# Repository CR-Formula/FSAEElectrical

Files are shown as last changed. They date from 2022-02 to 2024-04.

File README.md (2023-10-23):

# ISU Formula SAE Electrical Repo
This repo contains all the embedded and software development we have produced for the FSAE Team for its Electrical subsystem on cars CR-26 and CR-27.

## What's all included?

### 3D Prints
Housing for our electrical equipment placed on the car or for hand-held use remotely.

### Logs
Logs in CSV format of live data from testing the car on campus and live performance at competitions.

### Printed Circuit Board Designs
Selected schematics and PCB files used in our live data collection.

### Module Tests
This is code we utilize to test whether our electrical equipment is set up correctly and helps us troubleshoot problems.

### Nextion
Utilizing a Nextion display on our vehicle, this is the most up-to-date version dashboard each driver utilizes while driving to monitor the car's performance.

### Telemetry
Embedded C++ software written to our ESPs & Arduinos to handle reading, converting, and transporting CAN data from the car to our displays.

### Telemetry Viewer
This is a forked repo from Farrel (http://www.farrellf.com). In our version, we have added more visual modules, changed the behavior of existing modules, and changed the theme of the software as well.

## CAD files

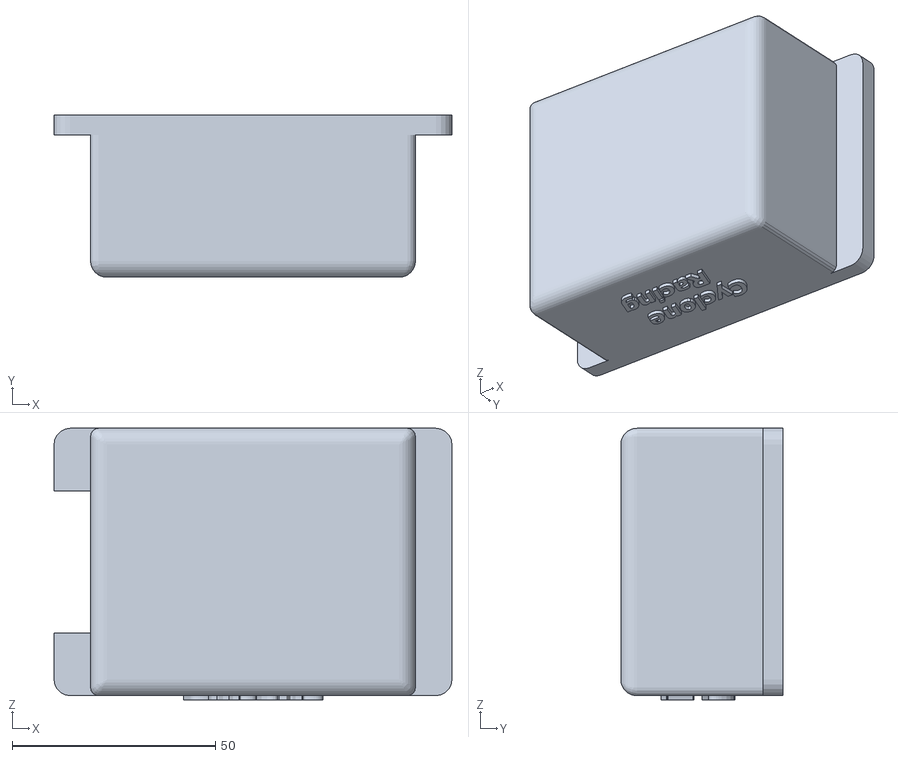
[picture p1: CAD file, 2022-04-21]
3D Prints/CR-26/Arduino_UnoLowerFinal2.stl
98.0 x 40.0 x 66.9

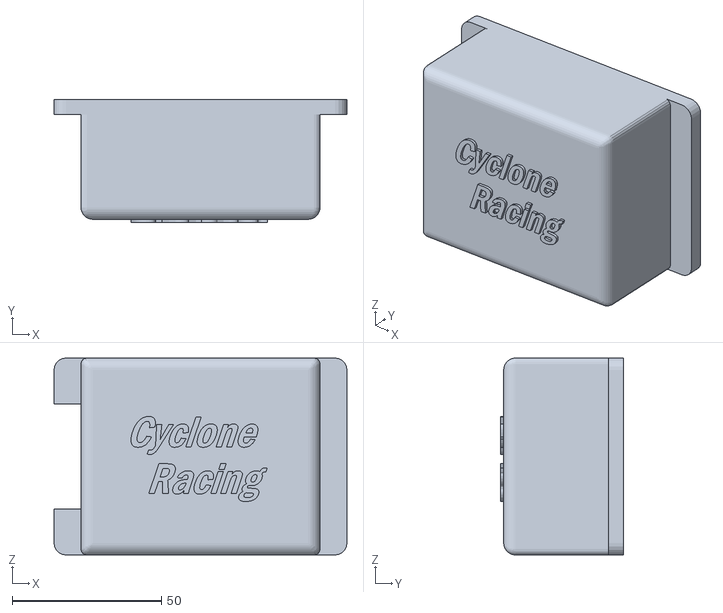
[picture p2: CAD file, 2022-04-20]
3D Prints/CR-26/Arduino_UnoLowerFinal.stl
98.0 x 41.0 x 65.9

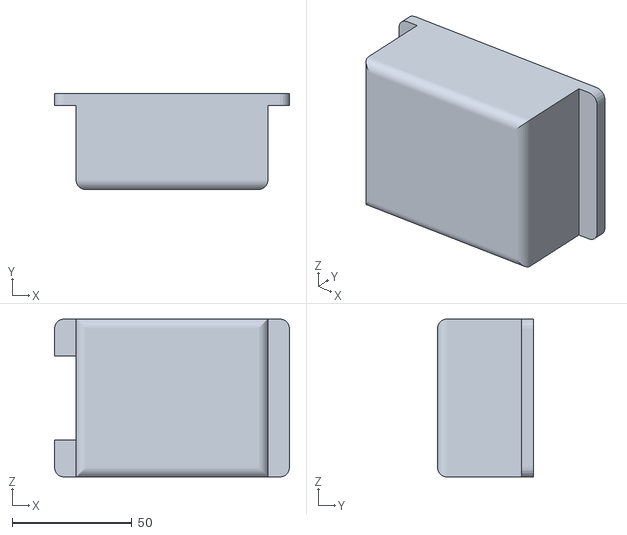
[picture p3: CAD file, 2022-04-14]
3D Prints/CR-26/Arduino_Unolower.stl
98.0 x 40.0 x 65.9

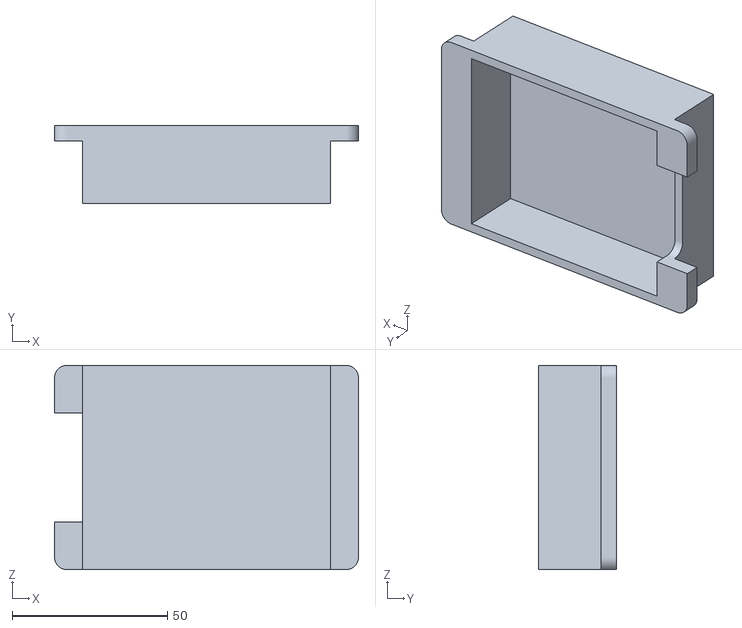
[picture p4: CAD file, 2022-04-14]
3D Prints/CR-26/Arduino_Uno_upper.stl
98.0 x 25.0 x 65.9

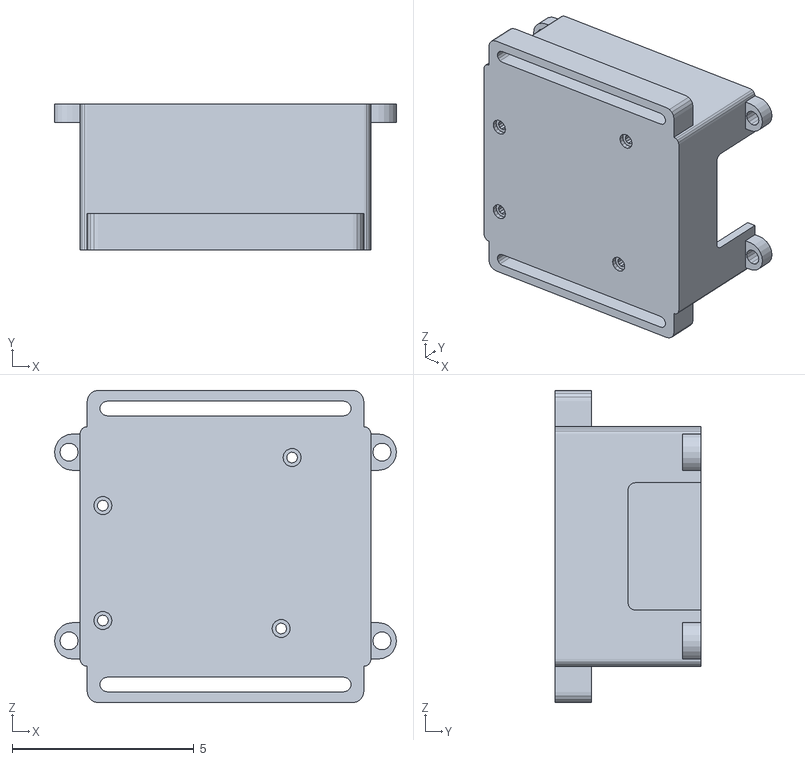
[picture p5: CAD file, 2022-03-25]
3D Prints/CR-26/Arduino_Uno2.stl
9.40 x 4.00 x 8.59

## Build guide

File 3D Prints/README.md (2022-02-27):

This folder is a place for all of Electrical to store 3D print files.
Currently just the arduino and ESP board boxes.

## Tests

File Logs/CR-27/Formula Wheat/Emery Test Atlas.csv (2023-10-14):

Format | AIM CSV File
Venue | Howe Hall International
Vehicle | CR27
User | Unknown
Data Source | AIM Data Logger
Comment | This data was sourced from Telemetry Viewer
Date | 2/5/1
Time | 11:12:13
Sample rate | 10000
Duration | 1.3343
Segment | NA
RPM | TPS | FOT | Ignition Angle | Lambda | AirT | CoolT | Latitude | Longitude | Speed | OilPressure | Fuel Pressure | Front Left Temp | Front Right Temp | Rear Left Temp | Rear Right Temp | Front Right Damper | Front Left Damper | Rear Right Damper | Rear Left Damper | Brake Pressure Front | Brake Pressure Rear | Brake Bias | AccX | AccY | AccZ | GyroX | GyroY | GyroZ | MagX | MagY | MagZ
RPM | TPS | FOT | Ignition Angle | Lambda | AirT | CoolT | Latitude | Longitude | Speed | OilPressure | Fuel Pressure | Front Left Temp | Front Right Temp | Rear Left Temp | Rear Right Temp | Front Right Damper | Front Left Damper | Rear Right Damper | Rear Left Damper | Brake Pressure Front | Brake Pressure Rear | Brake Bias | AccX | AccY | AccZ | GyroX | GyroY | GyroZ | MagX | MagY | MagZ
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

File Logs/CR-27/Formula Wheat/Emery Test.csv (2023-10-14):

Sample Number (10000 samples per second) | UNIX Timestamp (Milliseconds since 1970-01-01) | RPM (rpm) | TPS (%) | FOT (ms) | Ignition Angle (deg) | Lambda (Lambda) | AirT (C) | CoolT (C) | Latitude (Deg) | Longitude (Deg) | Speed (mph) | OilPressure (psi) | Fuel Pressure (psi) | Front Left Temp (C) | Front Right Temp (C) | Rear Left Temp (C) | Rear Right Temp (C) | Front Right Damper (mm) | Front Left Damper (mm) | Rear Right Damper (mm) | Rear Left Damper (mm) | Brake Pressure Front (psi) | Brake Pressure Rear (psi) | Brake Bias (%) | AccX (g) | AccY (g) | AccZ (g) | GyroX (deg) | GyroY (deg) | GyroZ (deg) | MagX (gauss) | MagY (gauss) | MagZ (gauss)0 | 1696179264662 | 0.0 | 0.0 | 0.0 | 0.0 | 0.0 | 0.0 | 0.0 | 0.0 | 0.0 | 0.0 | 0.0 | 0.0 | 0.0 | 0.0 | 0.0 | 0.0 | 0.0 | 0.0 | 0.0 | 0.0 | 0.0 | 0.0 | 0.0 | 0.0 | 0.0
1 | 1696179264662 | 0.0 | 0.0 | 0.0 | 0.0 | 0.0 | 0.0 | 0.0 | 0.0 | 0.0 | 0.0 | 0.0 | 0.0 | 0.0 | 0.0 | 0.0 | 0.0 | 0.0 | 0.0 | 0.0 | 0.0 | 0.0 | 0.0 | 0.0 | 0.0 | 0.0 | 0.0 | 0.0 | 0.0 | 0.0 | 0.0 | 0.0 | 0.0
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

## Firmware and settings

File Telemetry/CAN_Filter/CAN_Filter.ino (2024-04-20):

/*Iowa State Formula SAE Electrical Subsystem*/

#include <mcp_can.h> // CAN Bus Library
#include <SPI.h> // SPI Library
#include <Adafruit_LSM9DS1.h> // IMU Library
#include <Adafruit_Sensor.h> // Sensor Library
#include <RH_RF95.h> // LoRa Library
#include <math.h> // Math Library
#include <stdio.h> // Standard I/O Library
#include <stdlib.h> // Standard Library

#define FR_THERMO A1
#define ACC_X A15
#define ACC_Y A13
#define ACC_Z A14
#define FR_POT A12
#define RR_POT A12

void Accel_Cal(); // Calibrate Accelerometer
void Accel_Read(); // Read Accelerometer
void CAN_Data(); // Read in CAN Data
void Telemetry_Filter(); // Filter out extraneous values
void Send_Dash(); // Send values to update the dash display
void Suspension_Pot(); // Read in analog Suspension Damper Potentiometers
void Brake_Pressure(); // Read in analog Brake Pressure values
void Lora_Send(); // Send data over LoRa
void Print_Test_Data(); // Print test data to validate connections

// Stores the CAN Packet ID
long unsigned int rxId;
unsigned char len = 0;
// Length of the Buffer for Packet Data
unsigned char rxBuf[8];
// Stores the CAN packet serial message
char msgString[128];
static const int RxPin = 3;
static const int TxPin = 4;

// Sets INT to pin 2
#define CAN0_INT    2
// Sets CS
// MCP_CAN CAN0(10); // Uno
MCP_CAN CAN0(53); // Mega

// Defines for the LoRa Module Pins
#define RFM95_CS    49
#define RFM95_INT   3
#define RFM95_RST   7
#define RF95_FREQ   915.0

RH_RF95 rf95(RFM95_CS, RFM95_INT); // LoRa Module

// Holds all calculated Telemetry Data
typedef struct data_struct
{
  float RPM;           // RPM
  float TPS;           // TPS
  float FOT;           // Fuel Open Time
  float IA;            // Ignition Angle
  float Lam;           // Lambda
  float AirT;          // Air Temp
  float CoolT;         // Coolant Temp
  float Speed;         // Vehicle Speed
  float OilP;          // Oil Pressure
  float FRTemp;        // Front Right Brake Temp
  float RRTemp;        // Rear Right Brake Temp
  float FRPot;         // Front Right Suspension Damper
  float RRPot;         // Rear Right Suspension Damper
  float AccX;          // Accelerometer X Axis
  float AccZ;          // Accelerometer Z Axis
  float AccY;          // Accelerometer Y Axis
} data_struct;
data_struct telemetry;

// Stores Calculated Brake Bias Value
double brakeBias = 0;

// Variables used for filtering out extraneous values
int RPMLast;
float TPSLast;
float FOTLast;
float IALast;
float LamLast;
float AirTLast;
float CoolTLast;
float OilPLast;

// Variables for Accelerometer
int     XYZ_RAW[3];
int     XYZ_Cal_Offset[3];
double  XYZ_G[3];
uint8_t CALIBRATION_DONE;

char message[64]; // Buffer for Dash Message

char buf[sizeof(telemetry)]; // Buffer for data transmission

/**
 * @brief Initialize Peripherials and Sensors
 */
void setup() {
  Serial2.begin(115200); // Serial port 2 for Nextion

  // Init LoRa Module reset pin
  pinMode(RFM95_RST, OUTPUT);
  digitalWrite(RFM95_RST, HIGH);

  // Initializes MCP2515 running at 16MHz with a baudrate of 250kb/s and the masks and filters disabled.
  if (CAN0.begin(MCP_ANY, CAN_250KBPS, MCP_16MHZ) == CAN_OK)
    Serial.println("MCP2515 Initialized Successfully!");
  else
    Serial.println("Error Initializing MCP2515...");

  // Set MCP2515 operation to normal
  CAN0.setMode(MCP_NORMAL);

  // Configure the INT input pin
  pinMode(CAN0_INT, INPUT);

  // Reset LoRa Module
  digitalWrite(RFM95_RST, LOW);
  delay(10);
  digitalWrite(RFM95_RST, HIGH);
  delay(10);

  // Configure the LoRa Module
  while (!rf95.init()) {
    Serial.println("LoRa radio init failed");
    while (1);
  }
  Serial.println("LoRa radio init OK!");

  if (!rf95.setFrequency(RF95_FREQ)) {
    Serial.println("setFrequency failed");
    while (1);
  }
  Serial.print("Set Freq to: "); Serial.println(RF95_FREQ);
  rf95.setTxPower(23, false);
  // TODO: Look into Spreading Factor and bandwidth settings
  // SF11/500kHz  bitrate: 1760 Max   Payload Size: 109

  // Initialize Accelerometer
  CALIBRATION_DONE = 0;
  Serial.begin(115200);
  Accel_Cal();
}

/**
 * @brief Function to read Data fron PE3 ECU
 * @note All 2 byte data is stored [LowByte, HighByte]
 * @note Num = (LowByte + HighByte * 256) * resolution
 */
void CAN_Data() {
  if (!digitalRead(CAN0_INT))
  {
    // Read Id, length, and message data
    CAN0.readMsgBuf(&rxId, &len, rxBuf);

    // check for specific CAN ID. pull needed data, and repackage the data
    // Change if added Sensors
    if ((rxId & 0x1FFFFFFF) == 0x0CFFF048) {
      telemetry.RPM = (rxBuf[0] + rxBuf[1] * 256); // RPM
      telemetry.TPS = (rxBuf[2] + rxBuf[3] * 256) * 0.1; // Throttle Position Sensor
      telemetry.FOT = (rxBuf[4] + rxBuf[5] * 256) * 0.1; // Fuel Open Time
      telemetry.IA = (rxBuf[6] + rxBuf[7] * 256) * 0.1; // Igition Angle
    }
    if ((rxId & 0x1FFFFFFF) == 0x0CFFF148) {
      telemetry.Lam = (rxBuf[4] + rxBuf[5] * 256) * 0.001; // Lambda
    }
    if ((rxId & 0x1FFFFFFF) == 0x0CFFF548) {
      telemetry.AirT = (rxBuf[2] + rxBuf[3] * 256) * 0.1; // Air Temp
      telemetry.CoolT = (rxBuf[4] + rxBuf[5] * 256) * 0.1; // Coolant Temp
    }
    if ((rxId & 0x1FFFFFFF) == 0x0CFFF348) { 
      telemetry.OilP = (((rxBuf[6] + rxBuf[7] * 256) * 0.001) - .5) / 4.0 * 150.0; // Oil Pressure PSI
    }
  }
}

/**
 * @brief Reads data from the Analog Accelerometer
 * @note Applies calibration offset
 * 
 */
void Accel_Read() {
  telemetry.AccX = ((float)(analogRead(ACC_X) - XYZ_Cal_Offset[0]) / 170.667); /* Acceleration in g units */
  telemetry.AccY = ((float)(analogRead(ACC_Y) - XYZ_Cal_Offset[1]) / 170.667);
  telemetry.AccZ = ((float)(analogRead(ACC_Z) - XYZ_Cal_Offset[2]) / 170.667);
}

/**
 * @brief Calibrate Accelerometer
 * @note Reads in 5 values and averages them
 * 
 */
void Accel_Cal() {

  for (int i = 0; i < 5; i++) {
    XYZ_Cal_Offset[0] += analogRead(ACC_X);
    XYZ_Cal_Offset[1] += analogRead(ACC_Y);
    XYZ_Cal_Offset[2] += analogRead(ACC_Z);
  }

  XYZ_Cal_Offset[0] = XYZ_Cal_Offset[0] / 5;
  XYZ_Cal_Offset[1] = XYZ_Cal_Offset[1] / 5;
  XYZ_Cal_Offset[2] = XYZ_Cal_Offset[2] / 5;

  delay(1);
  CALIBRATION_DONE = 1;
}

/**
 * @brief Function to filter out extraneous values
 * @note Originaly written to reduce Time Slicing
 */
void Telemetry_Filter() {
  if (telemetry.RPM > 20000) {
      telemetry.RPM = RPMLast;
    }
    if (abs(TPSLast - telemetry.TPS) > 90 && TPSLast > 0) {
      telemetry.TPS = TPSLast;
    }
    if (abs(FOTLast - telemetry.FOT) > 10 && FOTLast > 0) {
      telemetry.FOT = FOTLast;
    }
    if (abs(IALast - telemetry.IA) > 50 && IALast > 0 || telemetry.IA > 40) {
      telemetry.IA = IALast;
    }
    if (abs(LamLast - telemetry.Lam) > 1 && LamLast > 0) {
      telemetry.Lam = LamLast;
    }
    if (abs(AirTLast - telemetry.AirT) > 25 && AirTLast > 0) {
      telemetry.AirT = AirTLast;
    }
    if (abs(CoolTLast - telemetry.CoolT) > 50 && CoolTLast > 0) {
      telemetry.CoolT = CoolTLast;
    }

  // Save last filtered values
  RPMLast = telemetry.RPM;
  TPSLast = telemetry.TPS;
  FOTLast = telemetry.FOT;
  IALast = telemetry.IA;
  LamLast = telemetry.Lam;
  AirTLast = telemetry.AirT;
  CoolTLast = telemetry.CoolT;
  OilPLast = telemetry.OilP;
}

/**
 * @brief Writes End Command to the Nextion Display
 */
void Nextion_CMD() {
    Serial2.write(0xff);
    Serial2.write(0xff);
    Serial2.write(0xff);
}

/**
 * @brief Send Data to the Dash
 * @note The telemetry values have to match Nextion Object names
 * @todo Add shift light functionality
 */
void Send_Dash() {
  // Send dash values as text objects

  sprintf(message, "%d\"", (int)telemetry.RPM);
  Serial2.print("rpm.txt=\"");
  Serial2.print(message); 
  Nextion_CMD();

  sprintf(message, "%d\"", (int)telemetry.CoolT);
  Serial2.print("waterTemp.txt=\"");
  Serial2.print(message);
  Nextion_CMD();

  sprintf(message, "%d\"", (int)telemetry.OilP);
  Serial2.print("oilPress.txt=\"");
  Serial2.print(message);
  Nextion_CMD();

  sprintf(message, "%d\"", (int)telemetry.FRTemp);
  Serial2.print("brakeFR.txt=\"");
  Serial2.print(message);
  Nextion_CMD();

  sprintf(message, "%d\"", (int)telemetry.RRTemp);
  Serial2.print("brakeRR.txt=\"");
  Serial2.print(message);
  Nextion_CMD();

  int rpmBar = telemetry.RPM / 160;
  Serial2.print("rpmBar.val=");
  Serial2.print(rpmBar);
  Nextion_CMD();

  // Send value for shift lights
  // Shift light range from 8525 - 15500
  if (telemetry.RPM > 7750) {
    int shiftlights = ((telemetry.RPM - 7750) * 80) / 7750;
    digitalWrite(5, shiftlights);
  }
}

/**
 * @brief Reads in suspension potentiometer values
 * @todo verify conversions
 */
void Suspension_Pot() {
  // telemetry.FLPot = ((double)analogRead(A0) * 50.0) / 1023.0;
  telemetry.FRPot = ((double)analogRead(FR_POT) * 50.0) / 1023.0;
  // telemetry.RLPot = ((double)analogRead(A2) * 50.0) / 1023.0;
  telemetry.RRPot = ((double)analogRead(RR_POT) * 50.0) / 1023.0;
}

/**
 * @brief Send the LoRa Packet
 * 
 */
void Lora_Send() {
  memcpy(buf, &telemetry, sizeof(telemetry)); // Copy data from struct
  rf95.send((uint8_t *)buf, sizeof(buf)); // Send Data
}

/**
 * @brief Caclulate Brake Temperature
 * @note Uses a thermocouple to calculate temperature
 * 
 */
void Brake_Temp() {
  int FRTemp = analogRead(FR_THERMO);

  // T = (V - 1.25) / .005
  telemetry.FRTemp = ((((double)FRTemp * 5) / 1023.0) - 1.25) / .005;
}

/**
 * @brief Function to print test data for debug
 * @note Comment this out when you upload to the car
 */
void Print_Test_Data() {
  Serial.println();
  Serial.println(telemetry.TPS);
  Serial.println(telemetry.FRTemp);
  Serial.println(brakeBias);
  Serial.println();
}

/**
 * @brief Super loop that calls all the telemetry functions
 * 
 */
void loop() {
  // function calls for each sensor/module
  CAN_Data();
  Brake_Temp();
  // Telemetry_Filter();
  // Suspension_Pot();
  Accel_Read();
  // Send_Dash();
  Lora_Send();

  Print_Test_Data();
  
  delay(1); // Delay for stability
}

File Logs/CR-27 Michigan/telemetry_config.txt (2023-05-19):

Telemetry Viewer v0.7 Settings

GUI Settings:

	tile column count = 6
	tile row count = 6
	time format = Only Time
	show 24-hour time = false
	show plot tooltips = true
	smooth scrolling = true
	show fps and period = false
	chart index for benchmarks = -1
	antialiasing level = 16

Communication Settings:

	port = UART: COM3
	uart baud rate = 115200
	tcp/udp port number = 8080
	packet type = CSV
	sample rate = 10000

11 Data Structure Locations:

	location = 0
	binary processor = null
	name = RPM
	color = 0xFF0000
	unit = rpm
	conversion factor a = 1.0
	conversion factor b = 1.0

	location = 1
	binary processor = null
	name = TPS
	color = 0xFF00FF
	unit = %
	conversion factor a = 1.0
	conversion factor b = 1.0

	location = 2
	binary processor = null
	name = Fuel Open Time
	color = 0x3333FF
	unit = ms
	conversion factor a = 1.0
	conversion factor b = 1.0

	location = 3
	binary processor = null
	name = Ignition Angle
	color = 0x66FF33
	unit = deg
	conversion factor a = 1.0
	conversion factor b = 1.0

	location = 4
	binary processor = null
	name = Lambda
	color = 0xFF9933
	unit = Lambda
	conversion factor a = 1.0
	conversion factor b = 1.0

	location = 5
	binary processor = null
	name = Air Temp
	color = 0x33FFFF
	unit = deg
	conversion factor a = 1.0
	conversion factor b = 1.0

	location = 6
	binary processor = null
	name = Coolant Temp
	color = 0x00CC00
	unit = deg
	conversion factor a = 1.0
	conversion factor b = 1.0

	location = 7
	binary processor = null
	name = Lat
	color = 0x009999
	unit = Deg
	conversion factor a = 1.0
	conversion factor b = 1.0

	location = 8
	binary processor = null
	name = Lng
	color = 0x009999
	unit = Deg
	conversion factor a = 1.0
	conversion factor b = 1.0

	location = 9
	binary processor = null
	name = Speed
	color = 0x009999
	unit = mph
	conversion factor a = 1.0
	conversion factor b = 1.0

	location = 10
	binary processor = null
	name = Oil Pressure
	color = 0xFF66FF
	unit = psi
	conversion factor a = 1.0
	conversion factor b = 1.0

Checksum:

	location = -1
	checksum processor = null

8 Charts:

	chart type = Dial
	top left x = 0
	top left y = 0
	bottom right x = 1
	bottom right y = 1
	normal datasets = 0
	bitfield edge states = 
	bitfield level states = 
	autoscale dial minimum = false
	manual dial minimum = 0.0
	autoscale dial maximum = false
	manual dial maximum = 15000.0
	sample count = 1000
	show dataset label = true
	show reading label = true
	show min/max labels = true
	show statistics = true

	chart type = Time Domain
	top left x = 2
	top left y = 0
	bottom right x = 3
	bottom right y = 1
	normal datasets = 5
	bitfield edge states = 
	bitfield level states = 
	duration type = Seconds
	duration = 3.0
	x-axis = Timestamps
	autoscale y-axis minimum = true
	manual y-axis minimum = -1.0
	autoscale y-axis maximum = true
	manual y-axis maximum = 1.0
	show x-axis title = true
	show x-axis scale = true
	show y-axis title = true
	show y-axis scale = true
	show legend = true
	cached mode = false
	over max warning = false
	max amount = 220

	chart type = Time Domain
	top left x = 4
	top left y = 0
	bottom right x = 5
	bottom right y = 1
	normal datasets = 6
	bitfield edge states = 
	bitfield level states = 
	duration type = Seconds
	duration = 3.0
	x-axis = Timestamps
	autoscale y-axis minimum = true
	manual y-axis minimum = -1.0
	autoscale y-axis maximum = true
	manual y-axis maximum = 1.0
	show x-axis title = true
	show x-axis scale = true
	show y-axis title = true
	show y-axis scale = true
	show legend = true
	cached mode = false
	over max warning = false
	max amount = 220

	chart type = Time Domain
	top left x = 2
	top left y = 2
	bottom right x = 3
	bottom right y = 3
	normal datasets = 2
	bitfield edge states = 
	bitfield level states = 
	duration type = Seconds
	duration = 3.0
	x-axis = Timestamps
	autoscale y-axis minimum = true
	manual y-axis minimum = -1.0
	autoscale y-axis maximum = true
	manual y-axis maximum = 1.0
	show x-axis title = true
	show x-axis scale = true
	show y-axis title = true
	show y-axis scale = true
	show legend = true
	cached mode = false
	over max warning = false
	max amount = 220

	chart type = Dial
	top left x = 4
	top left y = 2
	bottom right x = 5
	bottom right y = 3
	normal datasets = 3
	bitfield edge states = 
	bitfield level states = 
	autoscale dial minimum = false
	manual dial minimum = 10.0
	autoscale dial maximum = false
	manual dial maximum = 40.0
	sample count = 1000
	show dataset label = true
	show reading label = true
	show min/max labels = true
	show statistics = true

	chart type = Dial
	top left x = 0
	top left y = 2
	bottom right x = 1
	bottom right y = 3
	normal datasets = 1
	bitfield edge states = 
	bitfield level states = 
	autoscale dial minimum = false
	manual dial minimum = 0.0
	autoscale dial maximum = false
	manual dial maximum = 100.0
	sample count = 1000
	show dataset label = true
	show reading label = true
	show min/max labels = true
	show statistics = true
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

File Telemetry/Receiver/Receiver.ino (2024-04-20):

#include <SPI.h>
#include <RH_RF95.h>

// Uno
#define RFM95_CS    4
#define RFM95_INT   3
#define RFM95_RST   2
#define RF95_FREQ 915.0

typedef struct data_struct
{
  float RPM;           // RPM
  float TPS;           // TPS
  float FOT;           // Fuel Open Time
  float IA;            // Ignition Angle
  float Lam;           // Lambda
  float AirT;          // Air Temp
  float CoolT;         // Coolant Temp
  float Speed;         // Vehicle Speed
  float OilP;          // Oil Pressure
  float FRTemp;        // Front Right Brake Temp
  float RRTemp;        // Rear Right Brake Temp
  float FRPot;         // Front Right Suspension Damper
  float RRPot;         // Rear Right Suspension Damper
  float AccX;          // Accelerometer X Axis
  float AccZ;          // Accelerometer Z Axis
  float AccY;          // Accelerometer Y Axis
} data_struct;
data_struct telemetry;

uint32_t message[256]; // buffer for message

uint8_t buf[sizeof(telemetry)]; // buffer for message

RH_RF95 rf95(RFM95_CS, RFM95_INT);

/**
 * @brief Setup the LoRa module and Serial
 * @note The LoRa configuration must match the transmitter's configuration
 */
void setup() {
  pinMode(RFM95_RST, OUTPUT);
  digitalWrite(RFM95_RST, HIGH);

  Serial.begin(115200);
  delay(5);

  // Reset LoRa Module
  digitalWrite(RFM95_RST, LOW);
  delay(10);
  digitalWrite(RFM95_RST, HIGH);
  delay(10);

  // Must match the transmitter's settings in CAN_Filter.ino
  while (!rf95.init()) {
    Serial.println("LoRa radio init failed");
    while (1);
  }
  Serial.println("LoRa radio init OK!");

  if (!rf95.setFrequency(RF95_FREQ)) {
    Serial.println("setFrequency failed");
    while (1);
  }
  Serial.print("Set Freq to: "); Serial.println(RF95_FREQ);
  rf95.setTxPower(23, false);
}

/**
 * @brief Super Loop to print out the received message over COM port
 */
void loop() {
  if (rf95.available()) { // Check for new message
    uint8_t len = sizeof(buf);

    if (rf95.recv(buf, &len)) {
      memcpy(&telemetry, buf, sizeof(telemetry)); // Copy the message into the data struct
      // Print out the data struct
      Serial.print((int)telemetry.RPM);
      Serial.print(", ");
      Serial.print((int)telemetry.TPS);
      Serial.print(", ");
      Serial.print((double)telemetry.FOT);
      Serial.print(", ");
      Serial.print((double)telemetry.IA);
      Serial.print(", ");
      Serial.print((double)telemetry.Lam);
      Serial.print(", ");
      Serial.print((double)telemetry.AirT);
      Serial.print(", ");
      Serial.print((double)telemetry.CoolT);
      Serial.print(", ");
      Serial.print((double)telemetry.Speed);
      Serial.print(", ");
      Serial.print((double)telemetry.OilP);
      Serial.print(", ");
      Serial.print((double)telemetry.FRTemp);
      Serial.print(", ");
      Serial.print((double)telemetry.RRTemp);
      Serial.print(", ");
      Serial.print((double)telemetry.FRPot);
      Serial.print(", ");
      Serial.print((double)telemetry.RRPot);
      Serial.print(", ");
      Serial.print((double)telemetry.AccX);
      Serial.print(", ");
      Serial.print((double)telemetry.AccY);
      Serial.print(", ");
      Serial.print((double)telemetry.AccZ);
      Serial.println();
    }
  }
}

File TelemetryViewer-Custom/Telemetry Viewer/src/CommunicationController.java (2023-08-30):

import java.awt.Color;
import java.io.File;
import java.io.FileInputStream;
import java.io.IOException;
import java.io.InputStream;
import java.io.PipedInputStream;
import java.io.PipedOutputStream;
import java.io.PrintWriter;
import java.net.DatagramPacket;
import java.net.DatagramSocket;
import java.net.InetAddress;
import java.net.NetworkInterface;
import java.net.ServerSocket;
import java.net.Socket;
import java.net.SocketTimeoutException;
import java.nio.charset.StandardCharsets;
import java.nio.file.Files;
import java.nio.file.Paths;
import java.util.Arrays;
import java.util.Calendar;
import java.util.Date;
import java.util.Enumeration;
import java.util.LinkedList;
import java.util.List;
import java.util.Scanner;
import java.util.StringJoiner;
import java.util.function.Consumer;

import javax.swing.JPanel;
import javax.swing.SwingUtilities;
import com.fazecast.jSerialComm.SerialPort;

public class CommunicationController {
	
	public final static String PORT_UART = "UART"; // the DUT sends data over a serial port
	public final static String PORT_TCP  = "TCP";  // the DUT is a TCP client, so we spawn a TCP server
	public final static String PORT_UDP  = "UDP";  // the DUT sends UDP packets, so we listen for them
	public final static String PORT_TEST = "Test"; // dummy mode that generates test waveforms
	public final static String PORT_FILE = "File"; // dummy mode for importing CSV log files
	
	// volatile fields shared with threads
	private static volatile boolean connected = false;
	private static volatile String importFilePath = null;
	
	private static String port = PORT_UART;
	private static String portUsedBeforeImport = null;
	private static Packet packet = PacketCsv.instance;
	private static int    sampleRate = 10000;
	private static int    uartBaudRate = 9600;
	private static int    tcpUdpPort = 8080;
	private final static int MAX_TCP_IDLE_MILLISECONDS = 10000; // if connected but no new samples after than much time, disconnect and wait for a new connection
	private final static int MAX_UDP_PACKET_SIZE = 65507; // 65535 - (8byte UDP header) - (20byte IP header)
	
	private static String localIp = "[Local IP Address Unknown]";
	static {
		try { 
			String ips = "";
			Enumeration<NetworkInterface> interfaces = NetworkInterface.getNetworkInterfaces();
			while(interfaces.hasMoreElements()) {
				NetworkInterface ni = interfaces.nextElement();
				Enumeration<InetAddress> addresses = ni.getInetAddresses();
				while(addresses.hasMoreElements()) {
					InetAddress address = addresses.nextElement();
					if(address.isSiteLocalAddress() && !ni.getDisplayName().contains("VMware") && !ni.getDisplayName().contains("VPN"))
						ips += address.getHostAddress() + " or ";
				}
			}
			if(ips.length() > 0)
				localIp = ips.substring(0, ips.length() - 4);
		} catch(Exception e) {}
	}
	
	/**
	 * Sets the port and updates the GUI.
	 * If a connection currently exists, it will be closed first.
	 * 
	 * @param newPort    Communication.PORT_UART + ": port name" or .PORT_TCP or .PORT_UDP or .PORT_TEST or .PORT_FILE
	 */
	public static void setPort(String newPort) {
		
		// ignore if unchanged
		if(newPort.equals(port))
			return;
		
		// sanity check
		if(!newPort.startsWith(PORT_UART + ": ") &&
		   !newPort.equals(PORT_TCP) &&
		   !newPort.equals(PORT_UDP) &&
		   !newPort.equals(PORT_TEST) &&
		   !newPort.equals(PORT_FILE))
			return;
		
		// prepare
		if(isConnected())
			disconnect(null);
		if(port == PORT_TEST && newPort != PORT_TEST && newPort != PORT_FILE) {
			ChartsController.removeAllCharts();
			packet.reset();
		}
		
		// set
		if(port != PORT_FILE && newPort.equals(PORT_FILE))
			portUsedBeforeImport = port;
		port = newPort;
		CommunicationView.instance.setPort(newPort);
		
	}
	
	/**
	 * @return    The current port (Communication.MODE_UART + ": port name" or .MODE_TCP or .MODE_UDP or .MODE_TEST or .MODE_FILE)
	 */
	public static String getPort() {
		
		return port;
		
	}
	
	/**
	 * Gets names for every supported port (every serial port + TCP + UDP + Test)
	 *  
	 * @return    A String[] of port names.
	 */
	public static String[] getPorts() {
		
		SerialPort[] ports = SerialPort.getCommPorts();
		String[] names = new String[ports.length + 3];
		
		for(int i = 0; i < ports.length; i++)
			names[i] = "UART: " + ports[i].getSystemPortName();
		
		names[names.length - 3] = PORT_TCP;
		names[names.length - 2] = PORT_UDP;
		names[names.length - 1] = PORT_TEST;
		
		port = names[0];
		
		return names;
		
	}
	
	/**
	 * Sets the packet type, empties the packet, and updates the GUI.
	 * If a connection currently exists, it will be closed first.
	 * Any existing charts and datasets will be removed.
	 * 
	 * @param newType    One of the options from getPacketTypes().
	 */
	public static void setPacketType(String newType) {
		
		// ignore if unchanged
		if((newType.equals("CSV") && packet == PacketCsv.instance) || (newType.equals("Binary") && packet == PacketBinary.instance))
			return;
		
		// sanity check
		if(!newType.equals("CSV") &&
		   !newType.equals("Binary"))
			return;
		
		// prepare
		if(isConnected())
			disconnect(null);
		
		// set
		packet = newType.equals("CSV") ? PacketCsv.instance : PacketBinary.instance;
		packet.reset();
		CommunicationView.instance.setPacketType(newType);
		
	}
	
	/**
	 * @return    The current packet type.
	 */
	public static String getPacketType() {
		
		return packet.toString();
		
	}
	
	/**
	 * @return    A String[] of the supported packet types.
	 */
	public static String[] getPacketTypes() {
		
		return new String[] {"CSV", "Binary"};
		
	}
	
	/**
	 * @return    The GUI for defining the data structure.
	 */
	public static JPanel getDataStructureGui() {
		
		return packet.getDataStructureGui();
		
	}
	
	/**
	 * Sets the sample rate, and updates the GUI.
	 * The rate will be clipped to a minimum of 1.
	 * 
	 * @param newRate    Sample rate, in Hertz.
	 */
	public static void setSampleRate(int newRate) {
		
		// ignore if unchanged
		if(newRate == sampleRate)
			return;
		
		// sanity check
		if(newRate < 1)
			newRate = 1;
		
		// set
		sampleRate = newRate;
		CommunicationView.instance.setSampleRate(newRate);
		
	}
	
	/**
	 * @return    The current sample rate, in Hertz.
	 */
	public static int getSampleRate() {
		
		return sampleRate;
		
	}
	
	/**
	 * Sets the UART baud rate, and updates the GUI.
	 * The rate will be clipped to a minimum of 1.
	 * If a connection currently exists, it will be closed first.
	 * 
	 * @param newBaud    Baud rate.
	 */
	public static void setBaudRate(int newBaud) {
		
		// ignore if unchanged
		if(newBaud == uartBaudRate)
			return;
		
		// sanity check
		if(newBaud < 1)
			newBaud = 1;
		
		// prepare
		if(isConnected())
			disconnect(null);
		
		// set
		uartBaudRate = newBaud;
		CommunicationView.instance.setBaudRate(newBaud);
		
	}
	
	/**
	 * @return    The current baud rate.
	 */
	public static int getBaudRate() {
		
		return uartBaudRate;
		
	}
	
	/**
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

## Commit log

2022-02-19 added t viewer
    [monkey.stl]
2022-02-19 Add files via upload
    Test Log file with randomly generated values
    [Test Log File.csv]
2022-02-19 Add files via upload
    Original Config file for Telemetry Viewer
    [telemetry_config.txt]
2022-03-05 Error Correction
    Fixed MAC address definition
    Added testing methods
    Fixed minor errors
    [Receiver.ino]
2022-03-06 3/5 Workday
    Rest of the changes from Saturday workday
    Added more updated and complete config file for telemetry viewer
    [telemetry_config.txt]
2022-03-09 Completed Version 1
    First fully functional version of the telemetry system
    Includes updated config
    [telemetry_config.txt]
2022-03-21 TViewer Updated to Current Code
2022-03-25 It wasn't even the right box
    [Arduino_Uno2.stl]
2022-04-12 Testing Data
    Data collected from Testing on 4-12
    [Test Log File.csv, telemetry_config.txt]
2022-04-14 Added new models
    [Arduino_Uno_upper.stl, Arduino_Unolower.stl]
2022-04-20 Upper half will remain the same
    [Arduino_UnoLowerFinal.stl]
2022-04-21 Fixed Lamda value
    Added an offset to correct the Lambda value
    [Receiver.ino]
2022-04-30 Update TV
    [monkey.stl]
2022-04-30 Custom TV Added
    [monkey.stl]
2022-05-08 First Drive Updates
    A couple filtering changes and testing data from the first drive
    [First Drive 2.csv]
2022-05-10 New Receiver
    Swapped around the receiver MAC address and reorganized some of the code into other folders
    [CAN_Filter_GPS.ino, GPS_Test.ino, Receiver_GPS.ino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]
2022-05-11 Second Drive logs
    Logs from second test drive, also some file system cleanup stuff
    [5-7 First Drive 2.csv, First Drive 2.csv]
2022-06-17 Added Oil Pressure
    Added a CAN oil pressure data point
    [telemetry_config.txt]
2022-06-20 Added Logs
    Added Log Data from testing and comp
    [5-7 First Drive 2.csv, First Drive 2.csv, Test Log File.csv]
2022-07-29 Directory Cleanup
    Removed the Old no GPS folder and renamed the existing up to date code
    Also put the old 3D files into CR-26 specific folder
    [Arduino_Uno2.stl, Arduino_UnoLowerFinal.stl, Arduino_UnoLowerFinal2.stl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]
2022-08-28 Added Wheel Temp to Telemetry Viewer
    [monkey.stl]
2022-08-28 Fixing Telemetry Viewer
    [monkey.stl]
2022-09-21 Changed Telemetry Calculation
    Switched where the CAN data is converted to Telemetry values
    Switched to the use of EasyTransfer Library for Serial Communication
    Cant use I2C right now due to lacking code support for ESP32 Boards
    Still need to add sensors into the new code
2022-09-28 Code changes and test code
    Updated Telemetry code and added test code for wheel speed
2022-10-06 Time Domain - Overheating added + Wheel Speed
2022-10-14 Brake Temp Sensors
    Added all the code for the brake temp sensors, also added/cleaned up some comments and formatting
2022-10-19 Wheel Speed Reading labels fixed
    [Main.java]
2022-10-28 Added board compatibility
    Added support for MEGA
    Also added test file for Dash Development
2022-12-05 config/jar update
    [telemetry_config.txt]
2022-12-19 Fixed what Alex Removed smh -_-
    [Main.java]
2023-02-01 Added Wheelspeed test code
2023-02-13 Changed Overheating widget
    [telemetry_config.txt]
2023-02-20 Added Working Wheel Speed Example
2023-03-01 Added hall effect wheel speed code
2023-03-03 Added basic tests for IMU and Brake Pressure
2023-03-05 Added Analog Sensor variables
2023-03-07 Analog Sensor read functions
2023-03-26 Added IMU demo
2023-03-27 Added Fuel Pressure
2023-03-28 Updated Debug Printout
2023-04-08 Fixed Brake Temp Border
2023-04-11 Fixing Raspberry Code
2023-05-06 Brake Bias Calc
2023-05-06 Brake Bias
2023-05-09 Broken byte transfer progress
    [CAN_Filter.ino]
2023-05-14 Fixed CAN rate error
    [CAN_Filter.ino]
2023-05-14 I2C Rewrite file
2023-05-14 Added Brake Temp Printouts
2023-05-15 Changed Sensor Read Outs
2023-05-19 CR27 5-18 logsCR27 5-18 logsCR27 5-18 logsCR27 5-18 logsCR27 5-18 logsCR27 5-18 logsCR27 5-18 logsCR27 5-18 logsCR27 5-18 logsCR27 5-18 logsCR27 5-18 logsCR27 5-18 logsCR27 5-18 logsCR27 5-18 logsCR2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
    [5-7 First Drive 2.csv, Alex Comp 1 5-18.csv, Alex Comp 2 5-18.csv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]
2023-05-20 Logs and Spelling
    [Alex Comp 1 5-18.csv, Alex Comp 2 5-18.csv, Casey Autocross.csv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]
2023-08-30 Add atlas csv output (#20)
    * Remove bars plot
    * Add new CSV output option and code
    * Fixed headers & Units issue
    * Fixed Atlas Output
    [CommunicationController.java]
2023-10-14 Logs and Accel Changes
    [27_Config.txt, Emery Test Atlas.csv, Emery Test.csv]
2023-10-26 Updated some Wheelspeed Test Code
2023-10-26 Updated Wheelspeed Test Code
2023-12-01 Updated Wheelspeed Code
2024-03-03 Lora and Accelerometer Modules (#28)
    * Added Basic LoRa Code
    * LoRa Module Code
    * Updated LoRaWAN and Accel Files
    * Updated Accel Files
    * Renamed Analog Accel Example
    * Basic Functionality
    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
